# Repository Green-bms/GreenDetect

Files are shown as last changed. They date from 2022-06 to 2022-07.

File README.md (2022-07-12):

# GreenDetect
Opensource Wireless Sensor Network Platform (WSN) , for enviromental monitoring

## Description


Green Detect project was created with the aim of providing the community with a tool to monitor and control the environment.
The Green Detect network is independent of the Internet, so it can work even in geographic areas where the Internet is not present.
In the Green Detect local network it is possible to connect from 1 to 60 sensors that transmit their data via wireless through the ESP-NOW protocol to a computer where through the Green Detect application it is possible to monitor each individual sensor, detect alarm conditions, locate the sensors in an animated geographic map and record all acquisitions in order to collect all data for preventive and statistical purposes.
Each individual sensor module is powered by a supercapacitor (or Nimh batteries) charged by a solar panel.


Green Detect is Opensource: anyone can modify and improve the project, for example by adding new types of sensors.

## Web site
The project is described in detail at the following link: : https://hackaday.io/project/186064-green-detect

## Youtube presentation
https://youtu.be/CE9HRHpV6fQ
Subscribe please... :smile:

## Open source Development applications
The project was created using the following Open source applications:
- **KiCad** : to design sensor module
- **Arduino IDE** : to design the code of sensor module (ESP8266)
- **Visual Studio** : to design WIndows application in C# language
- **TinkerCad** : to design sensors and solar panel case for 3D printer

## Green Detect Windows application source code
The source code of Windows application is shared in the following repository: https://github.com/Green-bms/GreenDetect-Windows-Application

## Warning
This project is not commercial. This project is for educational and technological purposes.
No warrenty is foreseen.
Green BMS assumes no responsibility for any errors or inaccuracies that may appear in any documentation or file or any software that may be provided.
The use of this project is done entirely at your own risk and responsibility.
The use of this project may not be compliant with local laws or regulations.

## Open Source Hardware Certification
Green Detect has been certified as open source hardware by the Open Source Hardware Association, with the UID: IT000009.
Certificate link: (https://certification.oshwa.org/it000009.html)

## License

This work is licensed under a **Creative Commons Attribution-ShareAlike 4.0 International License**.
https://creativecommons.org/licenses/by-sa/4.0/

### You are free to:

**Share** — copy and redistribute the material in any medium or format

**Adapt**  — remix, transform, and build upon the material
for any purpose, even commercially.
This license is acceptable for Free Cultural Works.
The licensor cannot revoke these freedoms as long as you follow the license terms.

### Under the following terms:

**Attribution** — You must give appropriate credit, provide a link to the license, and indicate if changes were made. You may do so in any reasonable manner, but not in any way that suggests the licensor endorses you or your use.

**ShareAlike** — If you remix, transform, or build upon the material, you must distribute your contributions under the same license as the original.

**No additional restrictions** — You may not apply legal terms or technological measures that legally restrict others from doing anything the license permits.

### Notices:
You do not have to comply with the license for elements of the material in the public domain or where your use is permitted by an applicable exception or limitation.
No warranties are given. The license may not give you all of the permissions necessary for your intended use. For example, other rights such as publicity, privacy, or moral rights may limit how you use the material.

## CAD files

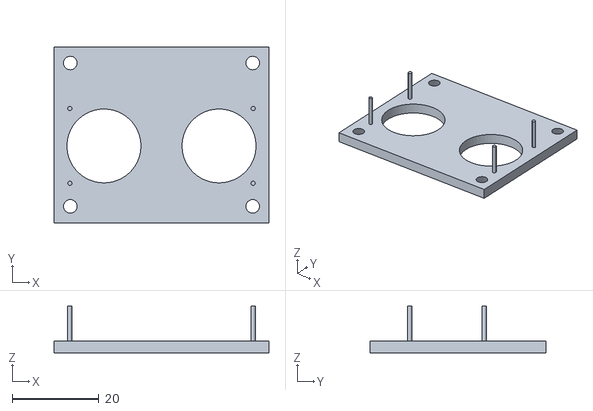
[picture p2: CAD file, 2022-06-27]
02 Sensors/Sensor type 01/3d printer box/SR04 case v0.3_cover.stl
49.5 x 40.5 x 10.8

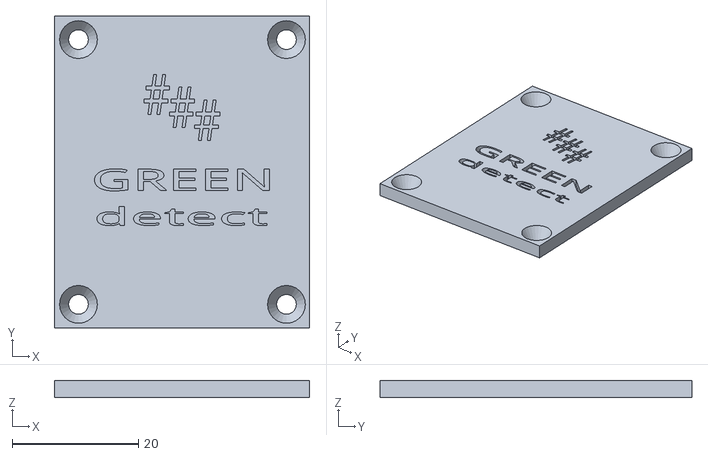
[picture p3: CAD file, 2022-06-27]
02 Sensors/Sensor type 02/3d printer box/Sensor2 case v0.0_cover.stl
40.5 x 49.5 x 2.75

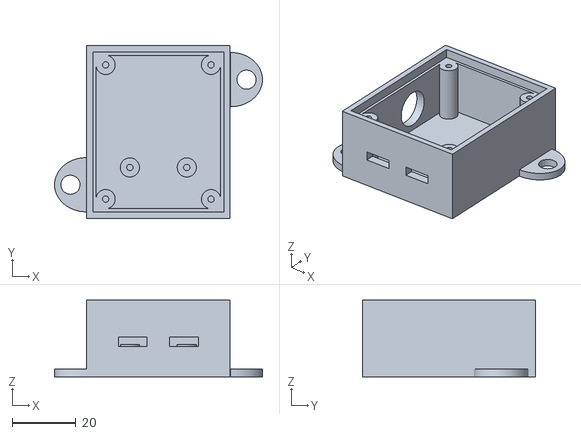
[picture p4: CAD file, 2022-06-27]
02 Sensors/Sensor type 04/3d printer box/Soil moinsture case v0.0.stl
65.1 x 54.0 x 24.0

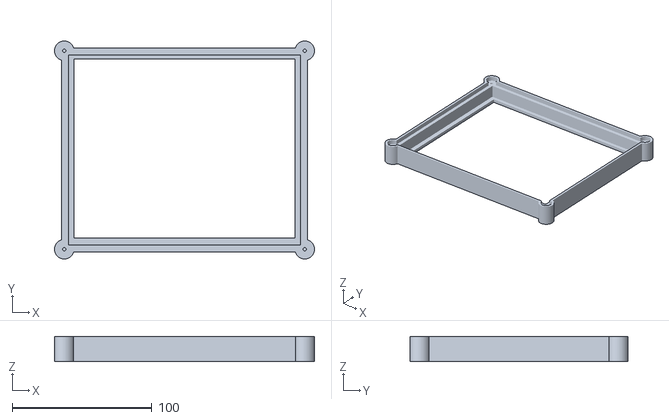
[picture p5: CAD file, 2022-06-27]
03 Solar panel/3d printer case/GreenDetect solar case front v.1.0.stl
186.0 x 156.0 x 18.0

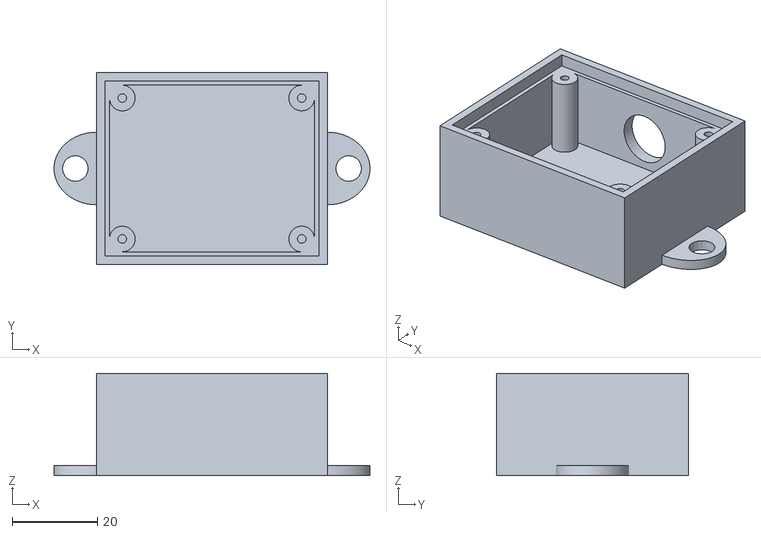
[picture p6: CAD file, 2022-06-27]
02 Sensors/Sensor type 01/3d printer box/SR04 case v0.3_box.stl
74.0 x 45.0 x 24.0

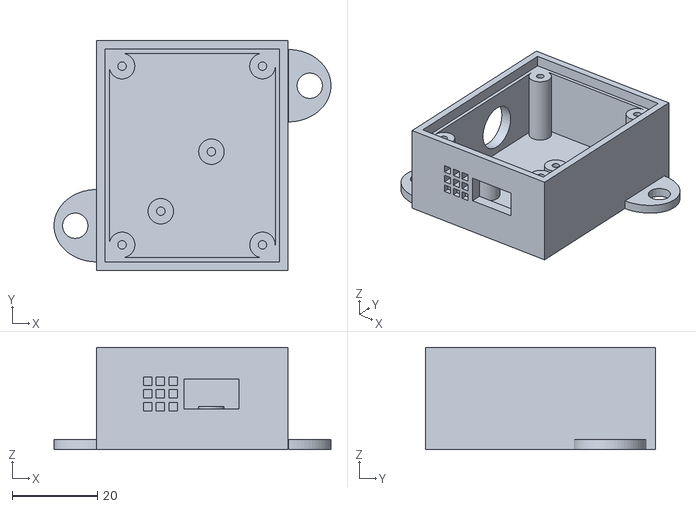
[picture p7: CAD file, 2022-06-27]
02 Sensors/Sensor type 02/3d printer box/Sensor2 case v0.0.stl
65.1 x 54.0 x 24.0

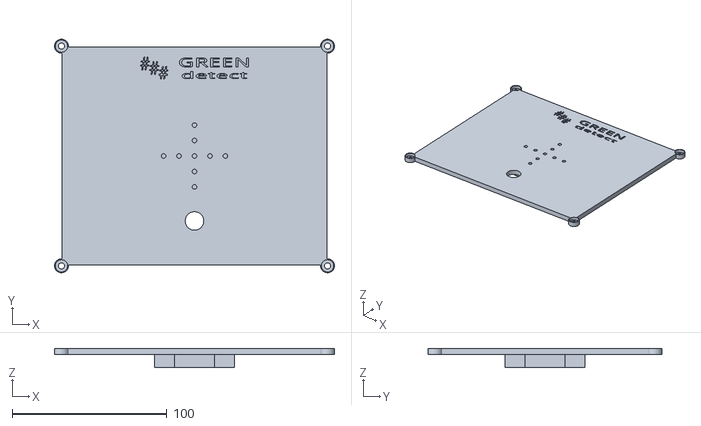
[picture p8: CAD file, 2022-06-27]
03 Solar panel/3d printer case/GreenDetect solar case back v.1.1.stl
181.0 x 151.0 x 12.5

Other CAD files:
02 Sensors/Sensor type 04/3d printer box/Soil moinsture case v0.0_cover.stl

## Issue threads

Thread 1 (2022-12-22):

Error installing Windows software

Arakistech, 2022-12-22:
When running setup.exe, I get this error: "El archivo GreenDetect.exe.config tiene un hash calculado distinto al especificado en el manifiesto."

Arakistech, 2022-12-22:
With the new download, I don´t get the error, but the program does not start.

Green-bms, 2022-12-22:
strange...

   try to check on windows app management if GreenDetect app is already present

   If yes, uninstall it and install again.

   If not try to restart the computer

   Da "Arakistech" ***@***.***
   A "Green-bms/GreenDetect" ***@***.***
   Cc "Green-bms" ***@***.***,"Comment" ***@***.***
   Data Thu, 22 Dec 2022 07:21:27 -0800
   Oggetto Re: [Green-bms/GreenDetect] Error installing Windows software (Issue #1)

   With the new download, I don´t get the error, but the program does not start.

   —
   Reply to this email directly, view it on GitHub, or unsubscribe.
   You are receiving this because you commented. Message ID: ***@***.***>

ahsanfi, 2023-02-09:
Hi, I also have error when installing the program. @Green-bms

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

**And this is the error detail:**
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

Green-bms, 2023-02-09:
Hi,

   first of all, check on windows app management if GreenDetect app is already present: If yes, uninstall it.

   After that, try to download Windows software from this link: https://hackaday.io/project/186064-green-detect

   go to files section and click on: 04 Win application.zip Bye. Sergio

   Da "Muhammad Ahsan Fillah Abadi" ***@***.***
   A "Green-bms/GreenDetect" ***@***.***
   Cc "Green-bms" ***@***.***,"Mention" ***@***.***
   Data Thu, 09 Feb 2023 01:31:27 -0800
   Oggetto Re: [Green-bms/GreenDetect] Error installing Windows software (Issue #1)

   Hi, I also have error when installing the program. @Green-bms

   And this is the error detail:

     PLATFORM VERSION INFO
     Windows : 10.0.22623.0 (Win32NT)
     Common Language Runtime : 4.0.30319.42000
     System.Deployment.dll : 4.8.9032.0 built by: NET481REL1
     clr.dll : 4.8.9105.0 built by: NET481REL1LAST_C
     dfdll.dll : 4.8.9032.0 built by: NET481REL1
     dfshim.dll : 10.0.22621.30000 (WinBuild.160101.0800)

     SOURCES
     Deployment url : file:///E:/OneDrive/OneDrive%20-%20Universitas%20Diponegoro/KEGIATAN%20LAIN/LOMBA/PKM%202023/SMART%20FOREST%20PROTECTOR/PROTOTYPE/GreenDetect-master/GreenDetect-master/04%20Win%20application/GreenDetect.application
     Application url : file:///E:/OneDrive/OneDrive%20-%20Universitas%20Diponegoro/KEGIATAN%20LAIN/LOMBA/PKM%202023/SMART%20FOREST%20PROTECTOR/PROTOTYPE/GreenDetect-master/GreenDetect-master/04%20Win%20application/Application%20Files/GreenDetect_1_0_0_44/GreenDetect.exe.manifest

     IDENTITIES
     Deployment Identity : GreenDetect.application, Version=1.0.0.44, Culture=neutral, PublicKeyToken=9ba089cdd6a5cde1, processorArchitecture=msil
     Application Identity : GreenDetect.exe, Version=1.0.0.44, Culture=neutral, PublicKeyToken=9ba089cdd6a5cde1, processorArchitecture=msil, type=win32

     APPLICATION SUMMARY
     * Installable application.

     ERROR SUMMARY
     Below is a summary of the errors, details of these errors are listed later in the log.
     * Activation of E:\OneDrive\OneDrive - Universitas Diponegoro\KEGIATAN LAIN\LOMBA\PKM 2023\SMART FOREST PROTECTOR\PROTOTYPE\GreenDetect-master\GreenDetect-master\04 Win application\GreenDetect.application resulted in exception. Following failure messages were detected:
          + File, GreenDetect.exe.config, has a different computed hash than specified in manifest.

     COMPONENT STORE TRANSACTION FAILURE SUMMARY
     No transaction error was detected.

     WARNINGS
     There were no warnings during this operation.

     OPERATION PROGRESS STATUS
     * [09/02/2023 16:28:43] : Activation of E:\OneDrive\OneDrive - Universitas Diponegoro\KEGIATAN LAIN\LOMBA\PKM 2023\SMART FOREST PROTECTOR\PROTOTYPE\GreenDetect-master\GreenDetect-master\04 Win application\GreenDetect.application has started.
     * [09/02/2023 16:28:43] : Processing of deployment manifest has successfully completed.
     * [09/02/2023 16:28:43] : Installation of the application has started.
     * [09/02/2023 16:28:43] : Processing of application manifest has successfully completed.
     * [09/02/2023 16:28:45] : Found compatible runtime version 4.0.30319.
     * [09/02/2023 16:28:45] : Request of trust and detection of platform is complete.

     ERROR DETAILS
     Following errors were detected during this operation.
     * [09/02/2023 16:28:46] System.Deployment.Application.InvalidDeploymentException (HashValidation)
          + File, GreenDetect.exe.config, has a different computed hash than specified in manifest.
          + Source: System.Deployment
          + Stack trace:
            at System.Deployment.Application.ComponentVerifier.VerifyFileHash(String filePath, Hash hash)
            at System.Deployment.Application.ComponentVerifier.VerifyFileHash(String filePath, HashCollection hashCollection)
            at System.Deployment.Application.ComponentVerifier.VerifyComponents()
            at System.Deployment.Application.DownloadManager.DownloadDependencies(SubscriptionState subState, AssemblyManifest deployManifest, AssemblyManifest appManifest, Uri sourceUriBase, String targetDirectory, String group, IDownloadNotification notification, DownloadOptions options)
            at System.Deployment.Application.ApplicationActivator.DownloadApplication(SubscriptionState subState, ActivationDescription actDesc, Int64 transactionId, TempDirectory& downloadTemp)
            at System.Deployment.Application.ApplicationActivator.InstallApplication(SubscriptionState& subState, ActivationDescription actDesc)
            at System.Deployment.Application.ApplicationActivator.PerformDeploymentActivation(Uri activationUri, Boolean isShortcut, String textualSubId, String deploymentProviderUrlFromExtension, BrowserSettings browserSettings, String& errorPageUrl, Uri& deploymentUri)
            at System.Deployment.Application.ApplicationActivator.PerformDeploymentActivationWithRetry(Uri activationUri, Boolean isShortcut, String textualSubId, String deploymentProviderUrlFromExtension, BrowserSettings browserSettings, String& errorPageUrl)
            --- End of stack trace from previous location where exception was thrown ---
            at System.Runtime.ExceptionServices.ExceptionDispatchInfo.Throw()
            at System.Deployment.Application.ApplicationActivator.PerformDeploymentActivationWithRetry(Uri activationUri, Boolean isShortcut, String textualSubId, String deploymentProviderUrlFromExtension, BrowserSettings browserSettings, String& errorPageUrl)
            at System.Deployment.Application.ApplicationActivator.ActivateDeploymentWorker(Object state)

     COMPONENT STORE TRANSACTION DETAILS
     No transaction information is available.

   —
   Reply to this email directly, view it on GitHub, or unsubscribe.
   You are receiving this because you were mentioned. Message ID: ***@***.***>

ahsanfi, 2023-02-09:
Thank you so much for your answer.
I have another question. Can I switch the Supercapacitor with 18650 Lithium Battery?

Sent from Mail<https://go.microsoft.com/fwlink/?LinkId=550986> for Windows

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

Green-bms, 2023-02-09:
No, you can't replace with lithium batteries: different voltage, different charging circuit.
You can replace Supercap with 2s Nimh batteries: this is an option of the project.
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

ahsanfi, 2023-02-09:
OK, thank you. Have you any preferences what Nimh batteries can I use?

Sent from Mail<https://go.microsoft.com/fwlink/?LinkId=550986> for Windows

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

Green-bms, 2023-02-09:
I suggest to use 2 x batteries AA 2800 mA Nimh, with a dedicated holder.
This is an example of batteries: https://www.amazon.com/POWEROWL-Rechargeable-Batteries-Capacity-Discharge/dp/B07M7JGTP7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
This is an example of holder: https://www.amazon.com/WAYLLSHINE-2Pcs-Battery-Holder-Leads/dp/B09V7Z4MT7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

ahsanfi, 2023-02-09:
Thank you so much ❤️

Sent from Mail<https://go.microsoft.com/fwlink/?LinkId=550986> for Windows

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

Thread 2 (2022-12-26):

Some of the components 3D is not visible in Kicad

Arakistech, 2022-12-26:
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

Arakistech, 2022-12-26:
I was not able to create the 3D model of the whole PCB maybe due to missing parts models. I would like to get the 3D model of the PCB to test it along with the enclosure 3D.

Green-bms, 2022-12-27:
Hi,
It looks like you don't have the main Kicad libraries installed.
download them from here: https://kicad.github.io/
to associate them with the Green detect project, you need to save the libraries in the following locations:

- symbols (.lib .dcm files) on C:\Program Files\KiCad\share\kicad\library
- footprints (.pretty folders) on C:\Program Files\KiCad\share\kicad\modules
- 3d models (.3dshapes folders) on C:\Program Files\KiCad\share\kicad\modules\packages3d\

Bye.

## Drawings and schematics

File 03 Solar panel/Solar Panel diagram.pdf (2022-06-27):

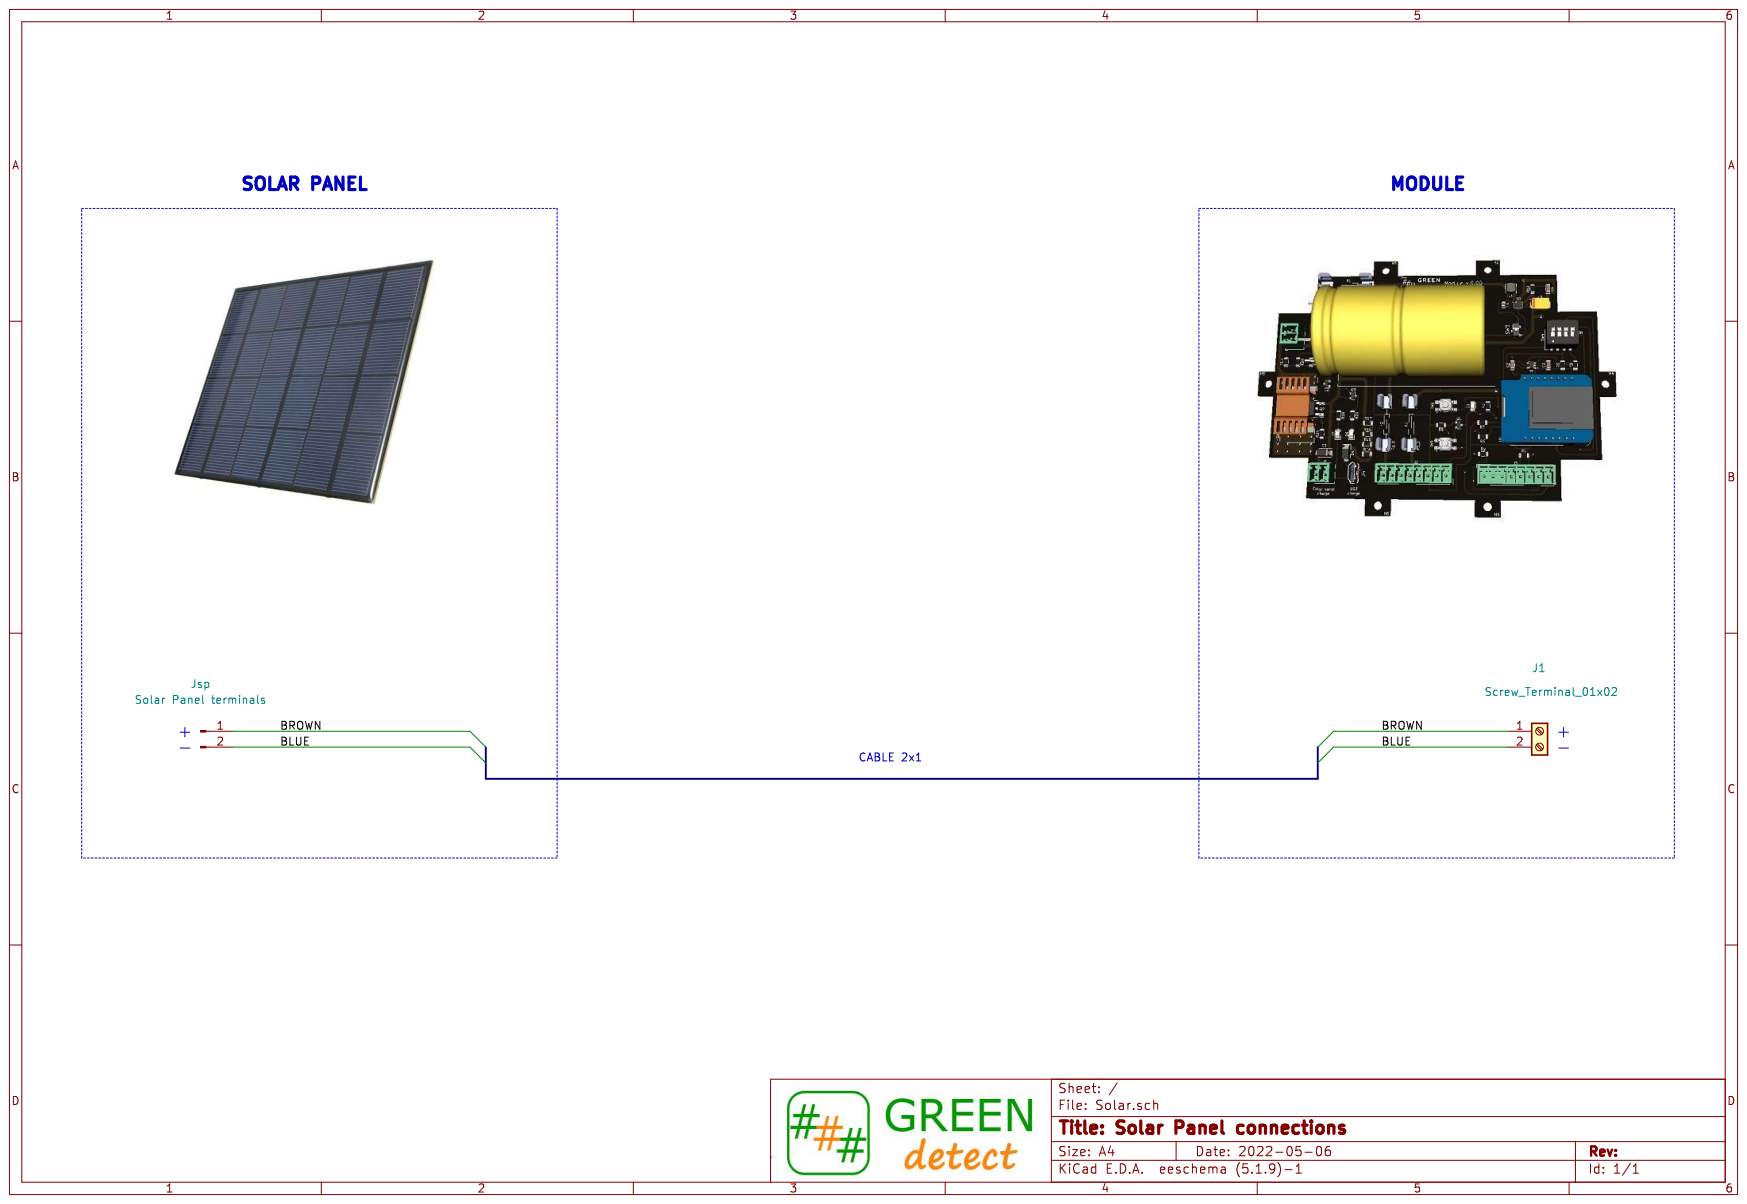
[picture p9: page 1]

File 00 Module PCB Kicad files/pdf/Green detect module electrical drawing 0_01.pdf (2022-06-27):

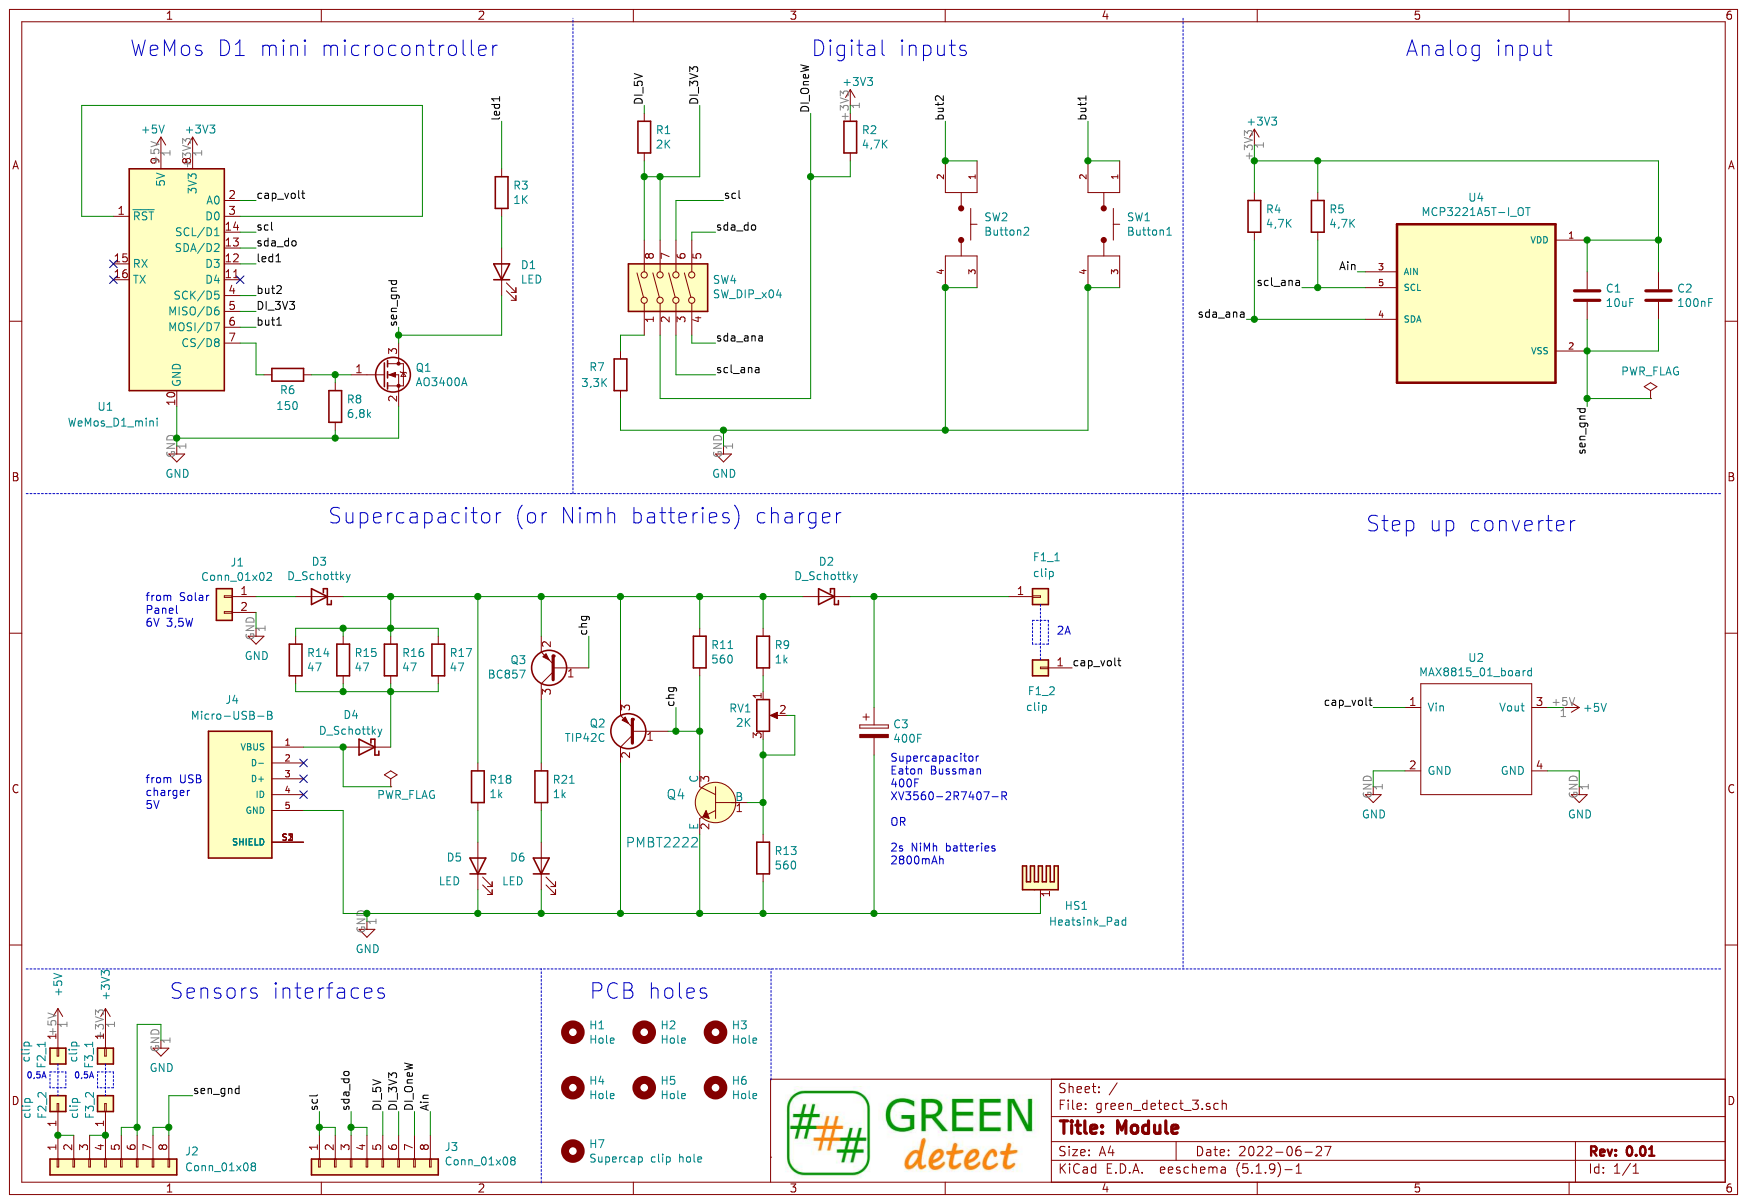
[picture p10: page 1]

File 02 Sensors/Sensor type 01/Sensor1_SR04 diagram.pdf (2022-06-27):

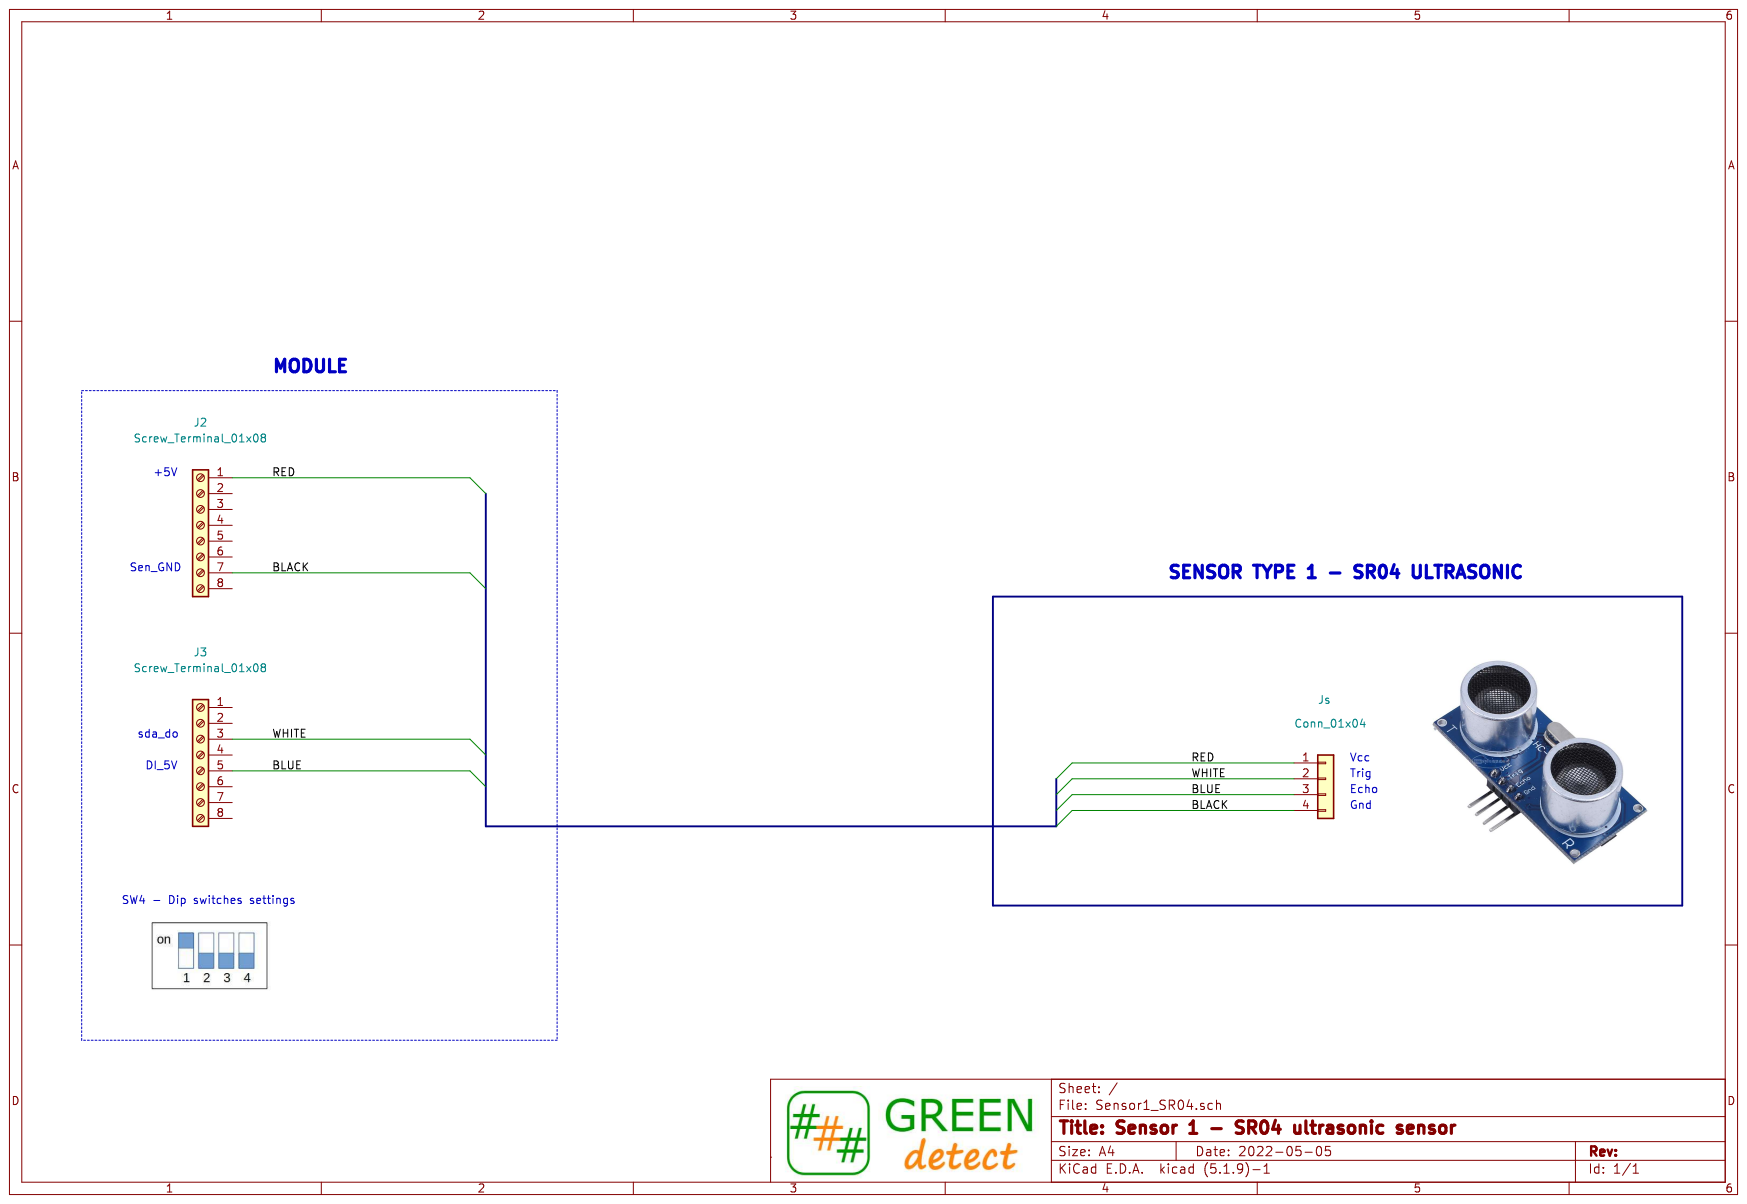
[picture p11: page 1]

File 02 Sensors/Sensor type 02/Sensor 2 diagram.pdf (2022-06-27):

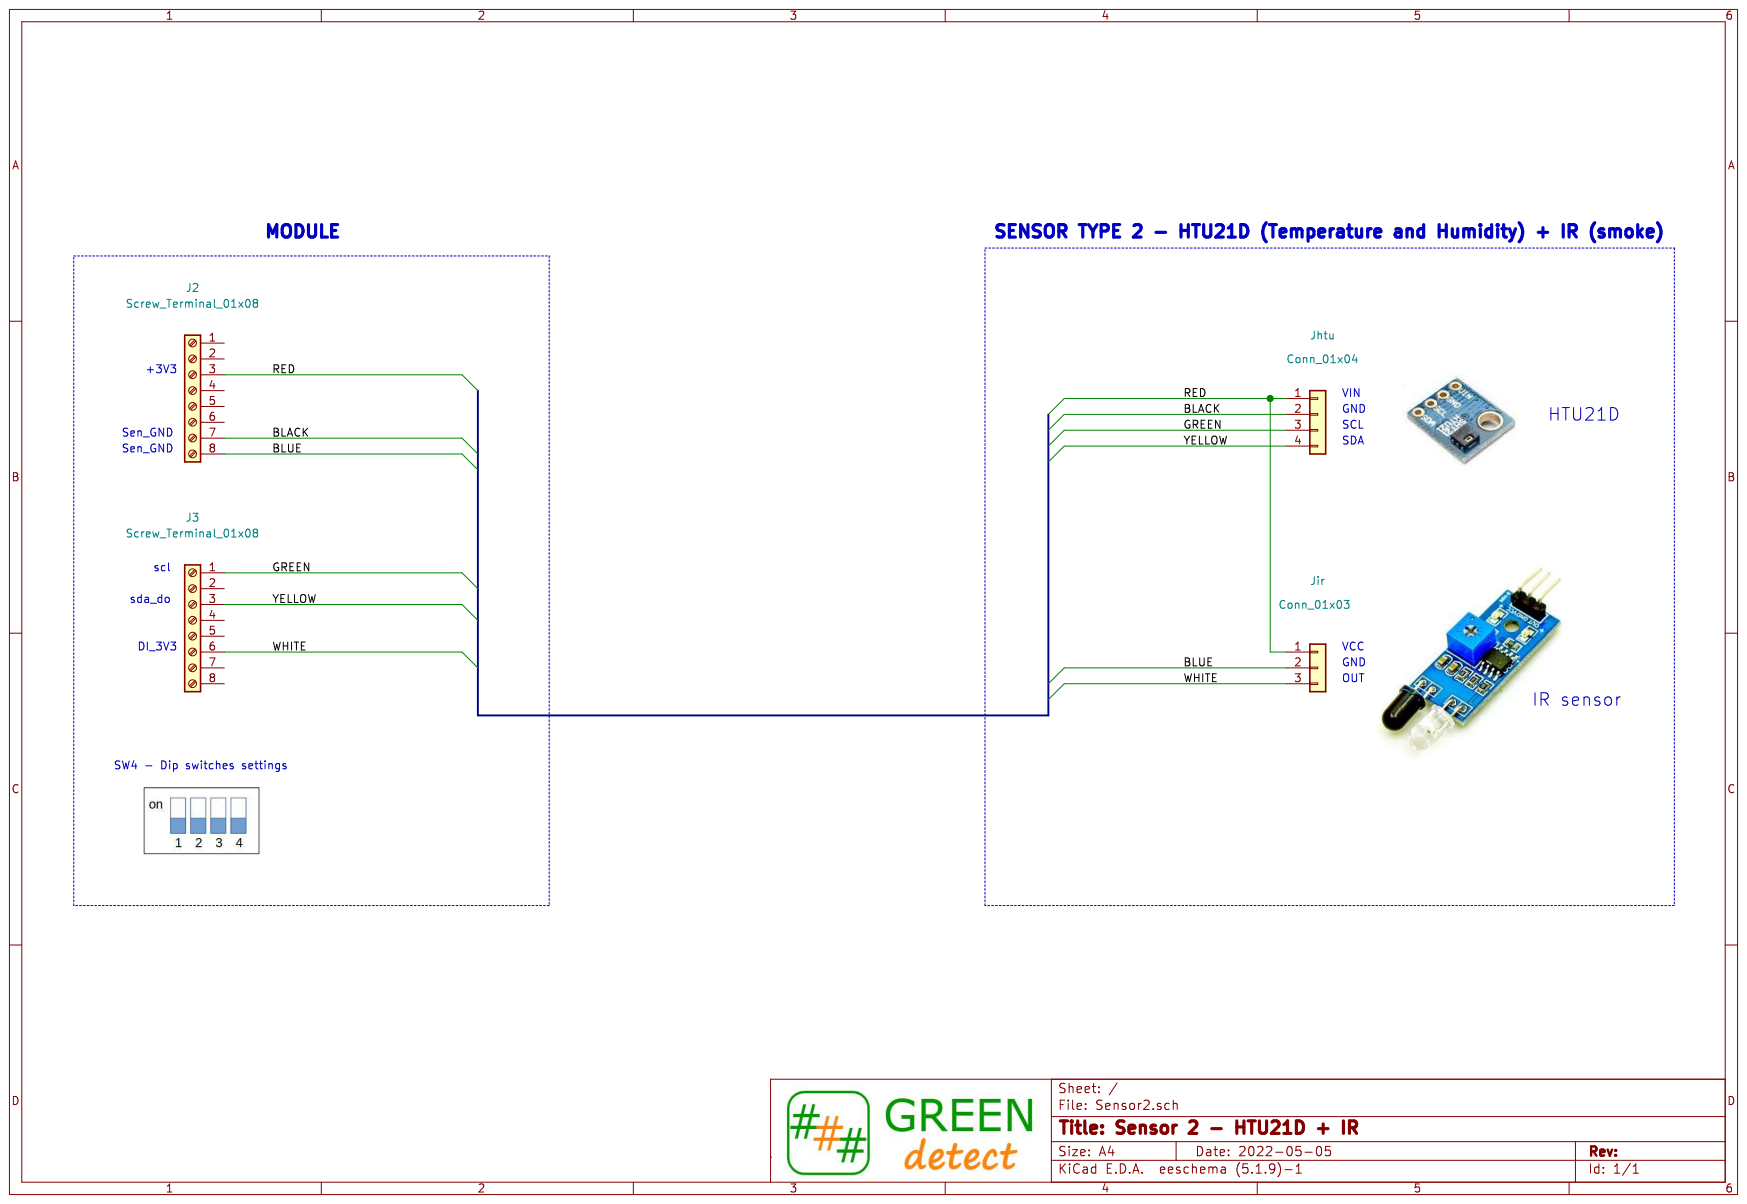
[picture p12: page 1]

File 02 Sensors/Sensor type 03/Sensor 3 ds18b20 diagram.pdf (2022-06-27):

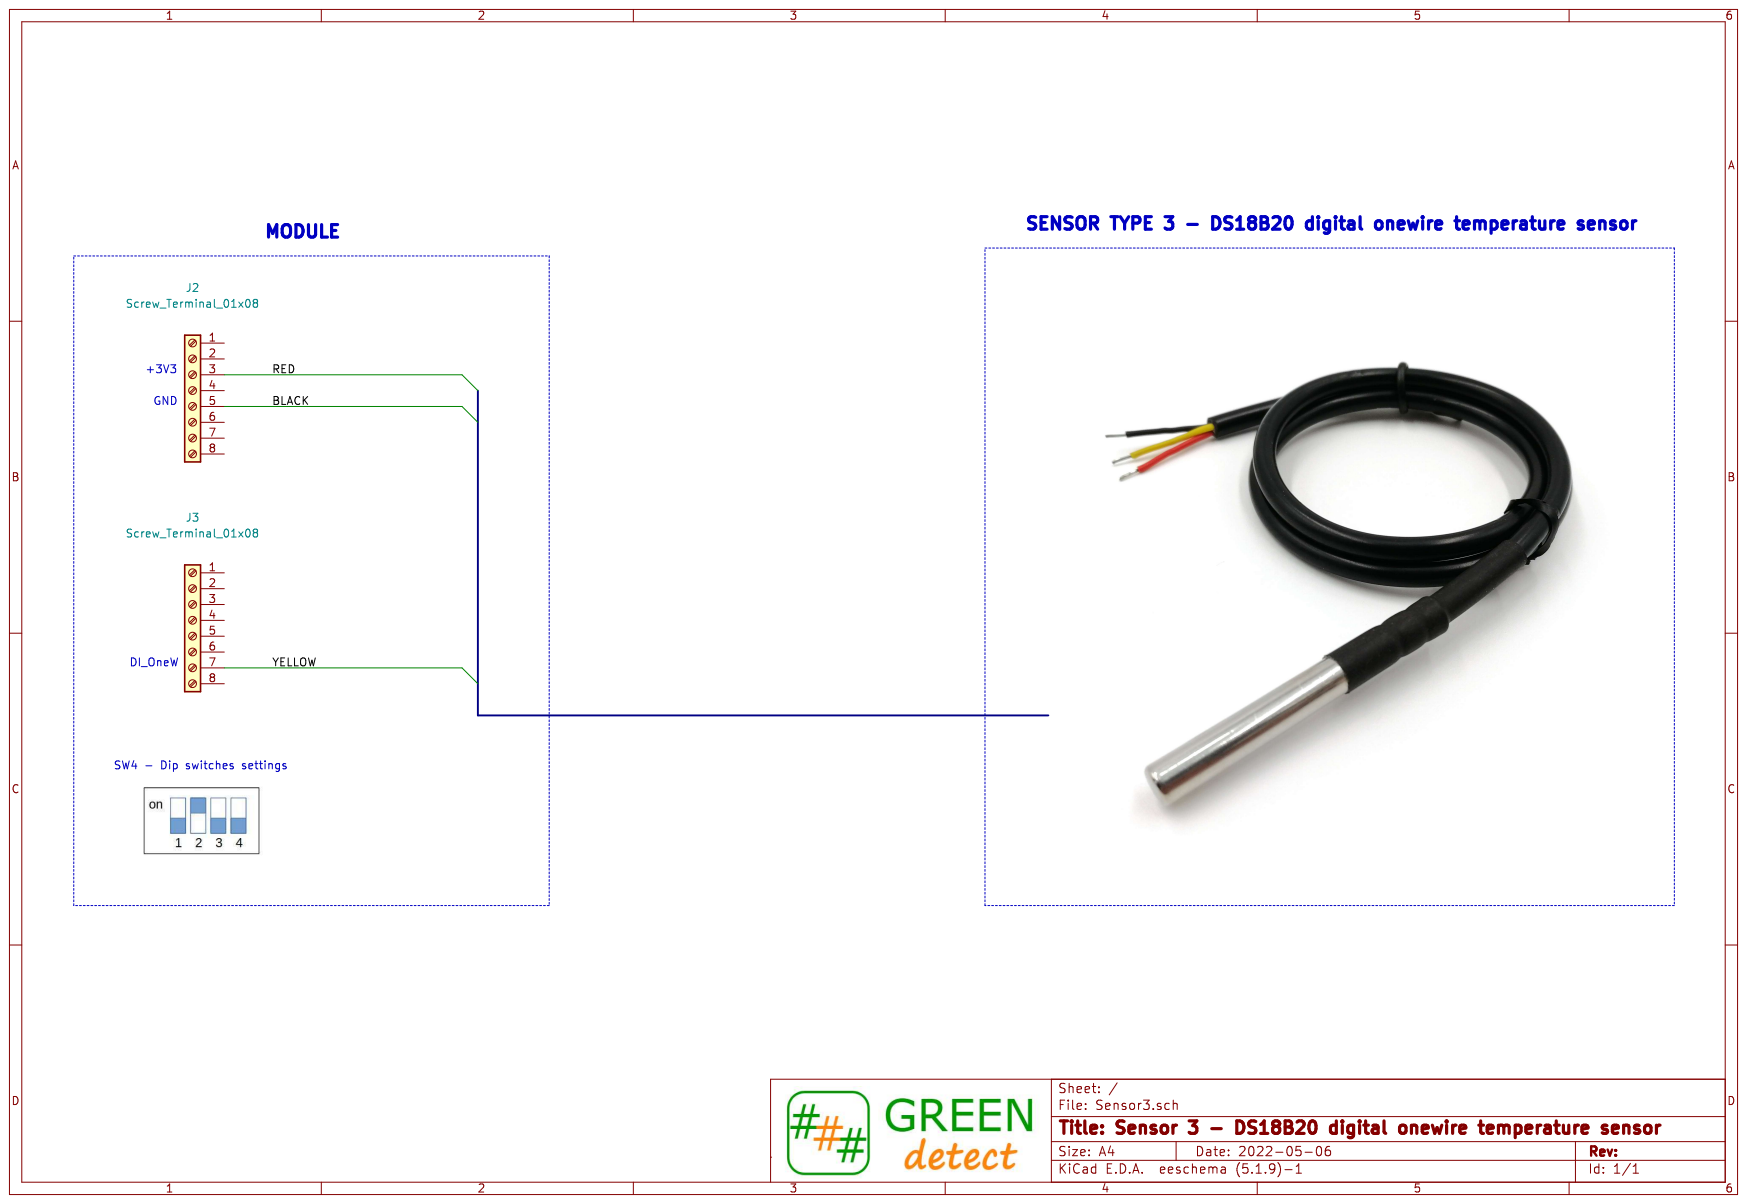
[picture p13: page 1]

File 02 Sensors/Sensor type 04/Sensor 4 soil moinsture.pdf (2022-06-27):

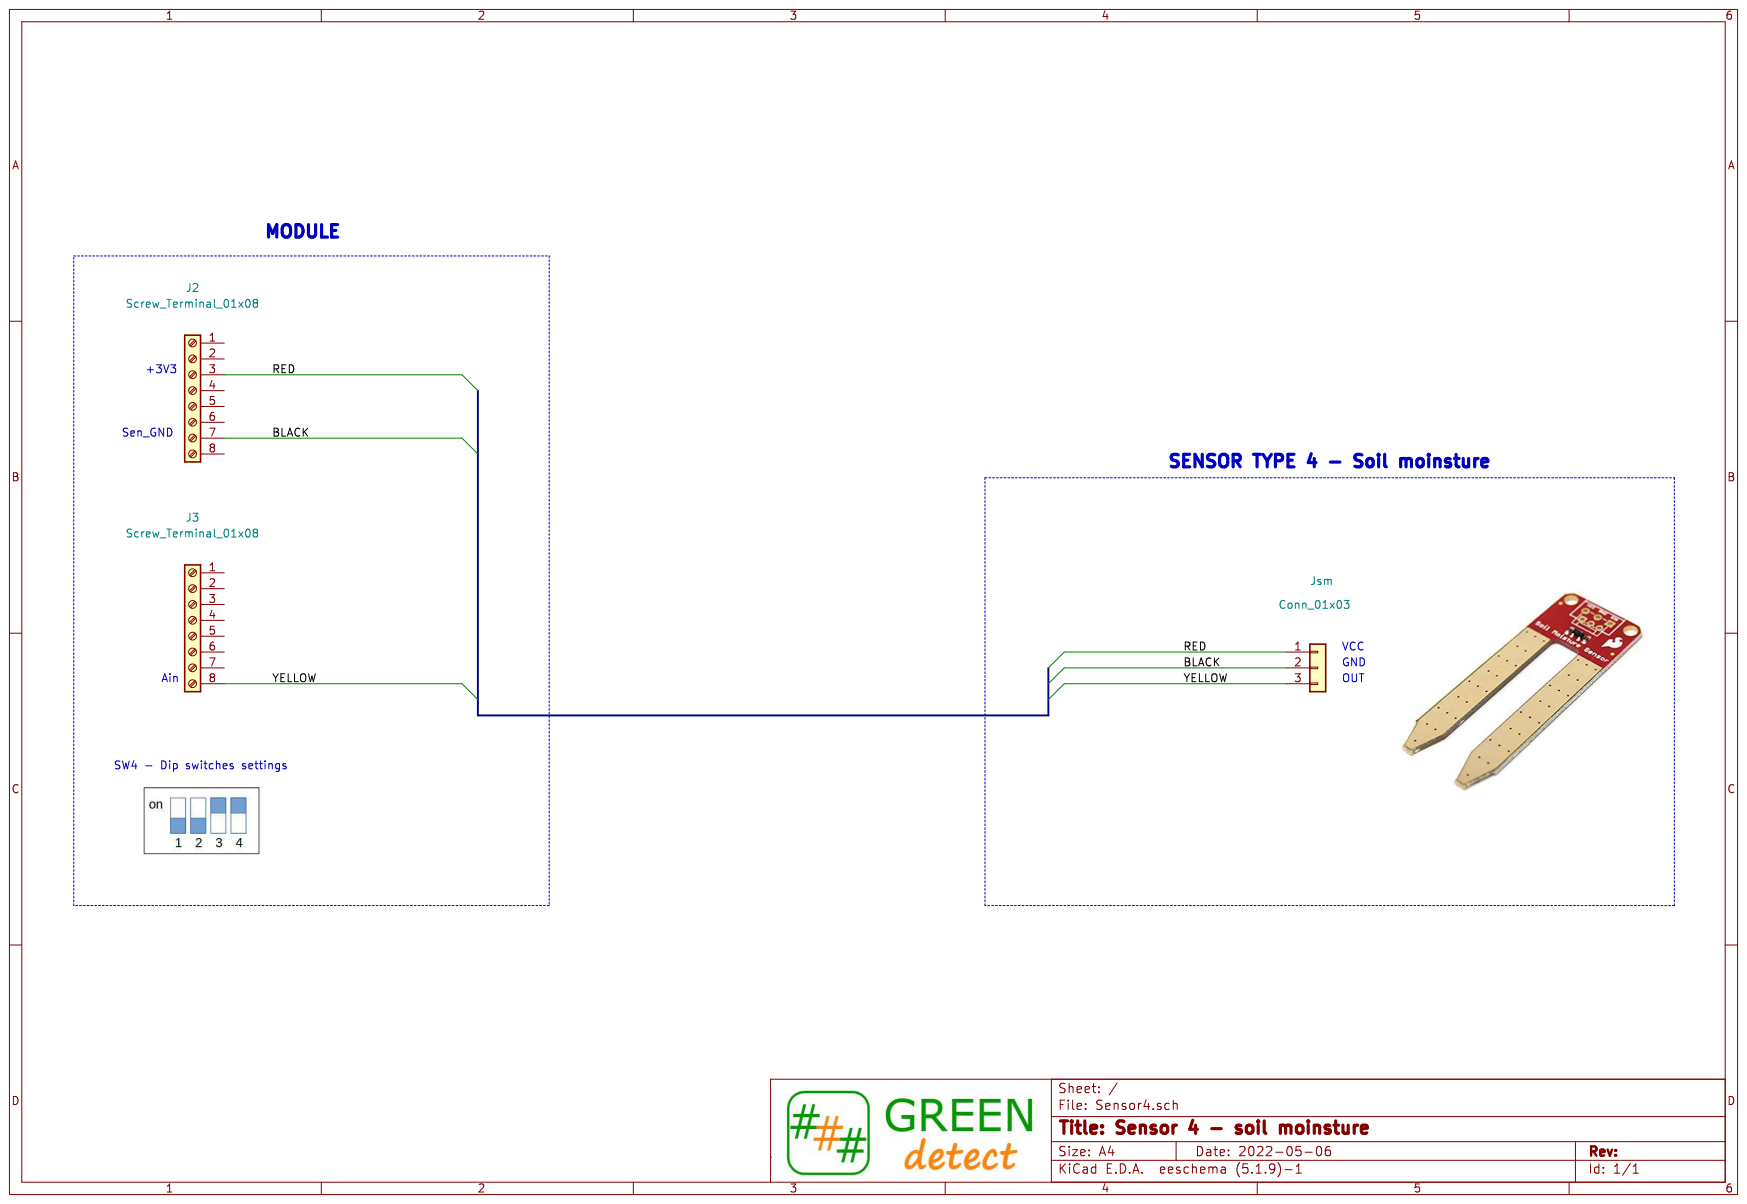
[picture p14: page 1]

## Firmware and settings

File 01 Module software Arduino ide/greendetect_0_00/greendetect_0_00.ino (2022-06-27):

/*
  Green Detect module


 Wireless Sensor Module with ESP-NOW protocol
 
 The module works according to the following steps:

1. sensor signal acquisition

2. receiving data from the previous form

3. data transmission to the next module

4. Deep sleep mode (30 seconds)


  Versions:

  - Ver. 0.00 date 27/06/2022 created by Sergio Ghirardelli (first release)

*/



#include <ESP8266WiFi.h>
#include <espnow.h>
#include "functions_5.h"
#include <EEPROM.h>
#include <Wire.h>
#include "SparkFunHTU21D.h"
#include <OneWire.h>
#include <DallasTemperature.h>

#include <Wire.h>
#include "MCP3X21.h"  






const uint8_t mcp3221_address = 0x4D;
const uint16_t ref_voltage = 3300;  // in mV
uint16_t MCP3221_channel;

MCP3221 mcp3221(mcp3221_address);



HTU21D htu21d_sensor;

unsigned long t, t0, t1, sample;

int i, n, z, k, x; //counters

//SR04 sensor
long duration, distance;
int distance_int;
int test_dist;

//htu21d sensor
float htu21d_temp, htu21d_hum;
int htu21d_temp_int, htu21d_hum_int;
byte htu21d_temp_byte, htu21d_hum_byte;

bool ir_input; //IR sensor
bool module_test; //module test

//supercap voltage measuring
int a0_channel, vx, vx_lim, vx_perc;
byte soc;

// Onewire DS18B20 temperature sensor
const int oneWireBus = 12;
OneWire oneWire(oneWireBus);
DallasTemperature sensors(&oneWire);
float onewire_temp;
int onewire_temp_int;

byte first_code; // code written in case of first use

//variables for program modes
unsigned long u_elapsed, u_count, da_elapsed, da_count;
unsigned long both_elapsed, both_count;
unsigned long net_elapsed, net_count;
bool osc, but_u, but_da, u, da, both, both_p, both_mem, prog, prog_p, prog_mem, prog_n, prog_mem2, osc_n, osc_mem, prog1, prog1_n, prog_mem3;
bool u_n, u_mem, da_n, da_mem, wdt_test;
int u_number, da_number, new_address, u_led_preset, u_led_elapsed, da_led_preset, da_led_elapsed, address, sleep_time, new_sleep_time, sensor_type, new_sensor_type, gain_offset, prog_step, deep_set;
byte last_set, fault_mode;


//variables used for transmission
byte send_step;
bool wait_n, wait_n_mem;
int app_time;
unsigned long lastTime;
unsigned long timerDelay;
unsigned long comp_time;
byte val1, val2, val3;
bool wait, wait_q;
unsigned long wait_elapsed, wait_count;
bool gateway_send;
bool deltime, deltime_q;
unsigned long deltime_elapsed, deltime_count;

unsigned long time_start, time_stop, life_start, life_stop; //variables to measure task time
unsigned long deep_time; // deep sleep time
bool send_ok;
bool pippo;

// Starting receiver address set
uint8_t broadcastAddress[] = {0x16, 0x16, 0x16, 0x16, 0x16, 0x00};

// Starting sensor module address
uint8_t newMACAddress[] = {0x16, 0x16, 0x16, 0x16, 0x16, 0x00};

// data structure
typedef struct struct_data {
  byte battery_soc[60];
  byte data1[60];
  byte data2[60];
  byte data3[60];
  byte sync_time;
  byte life;
  byte number;
} struct_data;

// structures
struct_data data_send;
struct_data data_rec;
struct_data data_internal;

//variables used to check previous module fault
bool timeout, timeout_q;
unsigned long timeout_elapsed, timeout_count, timeout_set;

//task time management
bool task, task_q;
unsigned long task_elapsed, task_count;
unsigned long advance_time;
long offset_time;

// Callback when data is sent
void OnDataSent(uint8_t *mac_addr, uint8_t sendStatus) {
  //Serial.println("Last Packet Send Status: ");
  if (sendStatus == 0) {
      send_ok = true;
  }
  else {
   // Serial.println("Delivery fail");
      send_ok = false;
  }
}


// Callback function that will be executed when data is received. Received data is copied in internal data variables.
void OnDataRecv(uint8_t * mac, uint8_t *incomingData, uint8_t len) {
  memcpy(&data_rec, incomingData, sizeof(data_rec));

  if ((address > 1) && (address <= 60)) {

    for ( i = 1; i < address; i++) {

      data_internal.battery_soc[i] = data_rec.battery_soc[i];
      data_internal.data1[i] = data_rec.data1[i];
      data_internal.data2[i] = data_rec.data2[i];
      data_internal.data3[i] = data_rec.data3[i];
    }

    data_internal.sync_time = data_rec.sync_time;
    data_internal.life = data_rec.life;
   
  }



  if (address == 99) {
    data_internal.number = data_rec.number;
   
    for ( i = 1; i <= data_internal.number; i++) {

      data_internal.battery_soc[i] = data_rec.battery_soc[i];
      data_internal.data1[i] = data_rec.data1[i];
      data_internal.data2[i] = data_rec.data2[i];
      data_internal.data3[i] = data_rec.data3[i];
    }

    data_internal.sync_time = data_rec.sync_time;
    data_internal.life = data_rec.life;
    
    gateway_send = true; 
    serial_transmission();

  }


}


void setup() {
  life_start = micros();
  
  // disable WIFI
  WiFi.mode(WIFI_OFF);

  //pin configuration
  pinMode(LED_BUILTIN, OUTPUT);
  pinMode(15, OUTPUT); //mosfet enable
  pinMode(12, INPUT); // Sensor Digital input (SR04 echo, IR, etc)
  pinMode(13, INPUT_PULLUP); // Button 1
  pinMode(14, INPUT_PULLUP); // Button 2
  pinMode(0, OUTPUT); //led 1



  //reading from EEprom, if first code is different from 114 it means that Eeprom is empty
  EEPROM.begin(9);
  first_code = EEPROM.read(3);

  if (first_code == 114) {
    address = EEPROM.read(0);
    last_set = EEPROM.read(2);
    sleep_time = EEPROM.read(4);
    sensor_type = EEPROM.read(6);
    fault_mode = EEPROM.read(8);
  }
  else {
    address = 0;
    last_set = 0;
    sleep_time = 50;
    sensor_type = 0;
    fault_mode = 0;
  }

  EEPROM.end();


 

  //Sensor Digital output (SR04 trig)
  if ((address != 99) && (sensor_type == 1)) {
    pinMode (4, OUTPUT);
  }

  //sensors supply mosfet activation
  digitalWrite(15, HIGH);

  //Onewire DS18B20 sensor setup
  if ((address != 99) && (sensor_type == 3)) {
    sensors.setWaitForConversion(false);
    sensors.requestTemperatures();
  }


  //MCP3221 ADC setup
  #if defined(ESP8266) || defined(ESP32)
  Wire.begin(SDA, SCL);
  mcp3221.init(&Wire);
  #else
  mcp3221.init();
  #endif


  //delay time for sensors start up
  delay (100);

  //variables initialization
  new_address = address;
  newMACAddress [5] = address;
  x = 0;
  k = 0;
  wdt_test = 0;
  lastTime = 0;
  timerDelay = 10;
  sample = 0;
  gateway_send = false;
  data_internal.life = 0;
  wait = true;
  task = false;
  timeout = false;
  send_step = 0;
  distance = 0;
  deep_set = 30;
  ir_input = false ;
  pippo = false;
  
  
  //module address management
  if (address == 0) {
    broadcastAddress [5] = 0x0; //module not addressed
  }
  else {
    if (last_set) {
      broadcastAddress [5] = 0x63; //when the module is the last, the recipient address is 0x63
    }
    else {
      broadcastAddress [5] = address + 1; //set the recipient address to the next address of the group
    }
  }


  //if both buttons are pressed, set the program mode
  if ((!digitalRead(13)) && (!digitalRead(14))) {
    prog_step = 1;
    prog = true;
    u_number = 1;
    da_number = 1;
  }
  else {
    prog_step = 0;
    prog = false;
    u_number = 0;
    da_number = 0;
  }

  //if only button2 is pressed, a memory reset is done
  if ((digitalRead(13)) && (!digitalRead(14))) {
    first_code = 0;
    EEPROM.begin(9);
    EEPROM.write(3, first_code);
    EEPROM.commit();
    EEPROM.end();
    delay (10);
    ESP.restart();
  }


  // Init Serial Monitor
  Serial.begin(115200);





  //Sensors reading
  if (address != 99) {

    //supercap voltage
    a0_channel = analogRead(A0);
    vx = map (a0_channel, 0, 1023, 0, 3100);
    vx_lim = constrain(vx, 1500, 3000);
    vx_perc = map (vx_lim, 1500, 3000, 0, 60);
    soc = byte (vx_perc);

    //sensor test button set the bit 7 of soc byte
    if (!digitalRead(13)) {
      module_test = true;
    }
    if (module_test) {
      bitSet(soc, 7);
    }

     //ADC analog input 
     MCP3221_channel = mcp3221.read();
    
    //sensor type = 0 --> repeater
    if (sensor_type == 0) {      
      val1 = 255;
      val2 = 255;
      val3 = 255;      
    }

    //sensor type = 1 --> SR04 ultrasonic distance sensor
    if (sensor_type == 1) {      
      digitalWrite(4, LOW);
      delayMicroseconds(2);
      digitalWrite(4, HIGH);
      delayMicroseconds(10);
      digitalWrite(4, LOW);
      duration = pulseIn(12, HIGH, 20000);
      distance = duration / 58.2;
      distance_int = int (distance);
      val1 = distance_int & 0xff;
      val2 = (distance_int >> 8);
      val3 = 0;    
    }

    //sensor type = 2 --> HTU21D temperature + humidity I2C sensor
    if (sensor_type == 2) {      
      htu21d_sensor.begin();
      htu21d_temp = htu21d_sensor.readTemperature();
      htu21d_hum = htu21d_sensor.readHumidity();
      float temp_x10 = htu21d_temp * 10;
      htu21d_temp_int = int (temp_x10);
      htu21d_hum_int = int (htu21d_hum);
      htu21d_hum_byte = byte (htu21d_hum_int);
      val1 = htu21d_temp_int & 0xff;
      val2 = (htu21d_temp_int >> 8);
      val3 = htu21d_hum_byte;
      if (!digitalRead(12)) {
        ir_input = true ;
      }
      if (ir_input) {
        bitSet(soc, 6);
      }
      
    }

    //sensor type = 3 --> Onewire DS18B20 temperature sensor
    if (sensor_type == 3) {
      
      onewire_temp = sensors.getTempCByIndex(0);
      float temp_x10 = onewire_temp * 10;
      onewire_temp_int = int (temp_x10);
      val1 = onewire_temp_int & 0xff;
      val2 = (onewire_temp_int >> 8);
      val3 = 0;
     
    }


    //sensor type = 4 --> Soil moisture sensor
   
    if (sensor_type == 4) {      
      val1 = MCP3221_channel & 0xff;
      val2 = (MCP3221_channel >> 8);
      val3 = 0;           
      }

    //to measure sensor type reading time 
    /*time_start = micros();
    
    time_stop = micros() - time_start; 
    Serial.println ("jk");
    Serial.println (time_stop); */



  }

  //sensors supply mosfet deactivation
  digitalWrite(15, LOW);

  // Set device as a Wi-Fi Station
  WiFi.mode(WIFI_STA);
  WiFi.setOutputPower(10); 
  wifi_set_macaddr(STATION_IF, &newMACAddress[0]);

  // Init ESP-NOW
  if (esp_now_init() != 0) {
    Serial.println("Error initializing ESP-NOW");
    return;
  }

  // Set ESP-NOW Role
  esp_now_set_self_role(ESP_NOW_ROLE_COMBO);

  // Once ESPNow is successfully Init, we will register for Send CB to
  // get the status of Trasnmitted packet
  esp_now_register_send_cb(OnDataSent);

  // Register peer
  esp_now_add_peer(broadcastAddress, ESP_NOW_ROLE_COMBO, 1, NULL, 0);

  // Register for a callback function that will be called when data is received
  esp_now_register_recv_cb(OnDataRecv);

  send_ok = false;
  deltime = false;
  deltime_q = false;
}




void loop() {

  

  /*Push buttons managements*/
  but_u = !digitalRead(13); //digital channels reading
  but_da = !digitalRead(14);
  u = TON(but_u, 50, u_elapsed, u_count); //buttons must be pressed for at least 50 msec
  da = TON(but_da, 50, da_elapsed, da_count);
  both = TON ((u and da), 3000, both_elapsed, both_count);//both buttons are pressed for 3 seconds
  both_p = PosTrig(both, both_mem); //positive edge of both variable
  prog_p = PosTrig(prog, prog_mem); //positive edge of prog: when program mode is set
  prog_n = NegTrig(prog, prog_mem2); //negative edge of prog: when program mode is reset
  prog1_n = NegTrig(prog1, prog_mem3); //negative edge of prog1: when program mode 1 is reset
  u_n = NegTrig(u, u_mem); //negative edge of u: when SW1 button is released
  da_n = NegTrig (da, da_mem); //negative edge of da: when SW2 button is released

  //oscillator for blinking
  if (millis() - t >= sample)
  {
    osc = !osc;
    t += sample;
  }


  /*Program mode or Normal mode calling*/
  if (prog_step == 1) {
    program();
  }

  else if (prog_step == 2) {
    prog_last();
  }


  else if (prog_step == 3) {
    prog_time();
  }

  else if (prog_step == 4) {
    prog_type();
  }

  else if (prog_step == 0) {
    normal();
  }


  
  test_dist =  data_internal.data2[1] << 8 | data_internal.data1[1];


  
  

  //serial monitor
/*  Serial.println (MCP3221_channel);
   Serial.print (" ");
    Serial.println (var);*/



}// end of loop



//normal mode
void normal () {


  if (prog_p) { // executed one time at the end of program mode. The new address set is stored and microcontroller reset

    digitalWrite(LED_BUILTIN, LOW); // both leds on to show the end of program mode
    digitalWrite(0, HIGH);
    address = new_address;
    sensor_type = new_sensor_type;


    EEPROM.begin(9);
    EEPROM.write(0, address);
    EEPROM.write(2, last_set);
    EEPROM.write(6, sensor_type);
    EEPROM.write(8, 0);

    if (first_code != 114) { //first EEprom address write
      first_code = 114;
      EEPROM.write(3, first_code);
    }
   /* if (address == 1) { //first EEprom address write
      sleep_time = new_sleep_time;
      EEPROM.write(4, sleep_time);
    }

    if ((address > 1) && (address <= 60)) { //first EEprom address write
      sleep_time = 60;
      EEPROM.write(4, sleep_time);
    }*/

    sleep_time = new_sleep_time;
    EEPROM.write(4, sleep_time);

    EEPROM.commit();
    EEPROM.end();

    newMACAddress [5] = address;
    n = address;
    delay(3000); //three seconds of freezing before starting the normal mode
    digitalWrite(0, LOW);
    ESP.restart();
  }


  if (both_p) {    //in case of pressing of both buttons for 3 seconds, system starts program mode
    prog = true;
    prog_step = 1;
  }

  //oscillator for gateway sending
  if (millis() - t >= 10)
  {
      if ((address==99) && (!gateway_send)) {
        Serial.println ("%");     
      }
    t += 10;
  }

  //task time management
  /*task_q = TON (!task, 120, task_elapsed, task_count);
    if (!task_q) {normal_sensor();}
    else {normal_send();}*/
  normal_send();

} // end of Normal mode




/*Program Mode to set the sensor module esp-now address*/
void program() {

  if (prog_p) {// executed one time at the start of program mode
    sample = 300;// sample time of leds blinking management (in msec)
    digitalWrite(15, HIGH);
    /*decrement of tens and units numbers*/
    u_number--;
    da_number--;
    u_led_elapsed = 0;
    da_led_elapsed = 0;
    digitalWrite(LED_BUILTIN, LOW); // both leds on to show the end of program mode
    digitalWrite(0, HIGH);
    delay(3000); //three seconds of freezing before starting the program mode
    digitalWrite(0, LOW);
    prog = false;
  }

  if (both_p) {    //in case of pressing of both buttons for 3 seconds, system soes to next program step
    if (new_address == 99) {
      prog = true;
      prog_step = 4;
    }
    else {
      prog = true;
      prog_step = 2;
    }

  }

  if (u_n) { //increment of units value after SW1 button release
    u_number++;
  }
  if (da_n) { //increment of tens value after SW2 button release
    da_number++;
  }
  if (u_number > 9) { //restart of units value
    u_number = 0;
  }
  if (da_number > 9) { //restart of tens value
    da_number = 0;
  }
  new_address = (da_number * 10) + u_number; //new address number calculation

  /*preset values of leds blink mangement */
  u_led_preset = u_number + 2;
  da_led_preset = da_number + 2;
  osc_n = NegTrig(osc, osc_mem);



  if (osc)
  {
    if ((u_led_elapsed >= 1) && (u_led_elapsed <= u_number)) { //blinking of Units led to show the set value
      digitalWrite(0, HIGH);
    }
    else  {
      digitalWrite(0, LOW);
    }

    if ((da_led_elapsed >= 1) && (da_led_elapsed <= da_number)) { //blinking of Tens led to show the set value
      digitalWrite(LED_BUILTIN, LOW);
    }
    else  {
      digitalWrite(LED_BUILTIN, HIGH);
    }

  }
  else
  {
    digitalWrite(0, LOW);
    digitalWrite(LED_BUILTIN, HIGH);
  }

  if (osc_n) //led blinking counters increment or reset every negative edge of the oscillator
  {
    u_led_elapsed++;
    if (u_led_elapsed > u_led_preset) {
      u_led_elapsed = 0;
    }
    da_led_elapsed++;
    if (da_led_elapsed > da_led_preset) {
      da_led_elapsed = 0;
    }
  }

}


/*Program step to set the sensor module as last of the network*/
void prog_last() {

  if (prog_p) { // executed one time at the end of program mode
    sample = 50; //led flashlight sample time (in msec)
    digitalWrite(LED_BUILTIN, LOW); // both leds on to show the end of program mode
    digitalWrite(0, HIGH);
    last_set = 0;
    delay(3000); //three seconds of freezing before starting the normal mode
    digitalWrite(0, LOW);
    prog = false;
  }


  if (both_p) {    //in case of pressing of both buttons for 3 seconds, system returnes to normal mode
    prog = true;
    prog_step = 4;
  }



  if (da_n) {
    last_set = 1; //set module as last of the whole battery pack
  }
  if (u_n) {
    last_set = 0; //set module as not the last of the whole battery pack
  }

  //if module is set as the last, builtin led flashlight, else led1 flashlights
  if (osc) {

    if (last_set == 1) {
      digitalWrite(LED_BUILTIN, LOW);
      digitalWrite(0, LOW);
    }
    else {
      digitalWrite(LED_BUILTIN, HIGH);
      digitalWrite(0, HIGH);
    }

  }

  else {

    digitalWrite(0, LOW);
    digitalWrite(LED_BUILTIN, HIGH);

  }
}


/*Program Mode to set the synchronization time for all the sensors (only if address is set to 1)*/
void prog_time() {

  if (prog_p) {// executed one time at the start of program mode
    sample = 300;// sample time of leds blinking management (in msec)

    /*decrement of tens and units numbers*/
    u_number = -1;
    da_number = -1;
    u_led_elapsed = 0;
    da_led_elapsed = 0;
    digitalWrite(LED_BUILTIN, LOW); // both leds on to show the end of program mode
    digitalWrite(0, HIGH);
    delay(3000); //three seconds of freezing before starting the program mode
    digitalWrite(0, LOW);
    prog = false;
  }

  if (both_p) {    //in case of pressing of both buttons for 3 seconds, system returnes to normal mode
    prog = true;
    prog_step = 0;
  }

  if (u_n) { //increment of units value after SW1 button release
    u_number++;
  }
  if (da_n) { //increment of tens value after SW2 button release
    da_number++;
  }
  if (u_number > 9) { //restart of units value
    u_number = 0;
  }
  if (da_number > 9) { //restart of tens value
    da_number = 0;
  }
  new_sleep_time = (da_number * 10) + u_number; //new address number calculation

  /*preset values of leds blink mangement */
  u_led_preset = u_number + 2;
  da_led_preset = da_number + 2;
  osc_n = NegTrig(osc, osc_mem);



  if (osc)
  {
    if ((u_led_elapsed >= 1) && (u_led_elapsed <= u_number)) { //blinking of Units led to show the set value
      digitalWrite(0, HIGH);
    }
    else  {
      digitalWrite(0, LOW);
    }

    if ((da_led_elapsed >= 1) && (da_led_elapsed <= da_number)) { //blinking of Tens led to show the set value
      digitalWrite(LED_BUILTIN, LOW);
    }
    else  {
      digitalWrite(LED_BUILTIN, HIGH);
    }

  }
  else
  {
    digitalWrite(0, LOW);
    digitalWrite(LED_BUILTIN, HIGH);
  }

  if (osc_n) //led blinking counters increment or reset every negative edge of the oscillator
  {
    u_led_elapsed++;
    if (u_led_elapsed > u_led_preset) {
      u_led_elapsed = 0;
    }
    da_led_elapsed++;
    if (da_led_elapsed > da_led_preset) {
      da_led_elapsed = 0;
    }
  }

}



/*Program Mode to set the sensor type*/
void prog_type() {

  if (prog_p) {// executed one time at the start of program mode
    sample = 300;// sample time of leds blinking management (in msec)

    /*decrement of tens and units numbers*/
    u_number = -1;
    da_number = -1;
    u_led_elapsed = 0;
    da_led_elapsed = 0;
    digitalWrite(LED_BUILTIN, LOW); // both leds on to show the end of program mode
    digitalWrite(0, HIGH);
    delay(3000); //three seconds of freezing before starting the program mode
    digitalWrite(0, LOW);
    prog = false;
  }

  if (both_p) {    //in case of pressing of both buttons for 3 seconds, system returnes to normal mode

    if (new_address == 1) {
      prog = true;
      prog_step = 3;
    }
    else {
      prog = true;
      prog_step = 0;
    }

   

  }

  if (u_n) { //increment of units value after SW1 button release
    u_number++;
  }
  if (da_n) { //increment of tens value after SW2 button release
    da_number++;
  }
  if (u_number > 9) { //restart of units value
    u_number = 0;
  }
  if (da_number > 9) { //restart of tens value
    da_number = 0;
  }
  new_sensor_type = (da_number * 10) + u_number; //new address number calculation

  /*preset values of leds blink mangement */
  u_led_preset = u_number + 2;
  da_led_preset = da_number + 2;
  osc_n = NegTrig(osc, osc_mem);



  if (osc)
  {
    if ((u_led_elapsed >= 1) && (u_led_elapsed <= u_number)) { //blinking of Units led to show the set value
      digitalWrite(0, HIGH);
    }
    else  {
      digitalWrite(0, LOW);
    }

    if ((da_led_elapsed >= 1) && (da_led_elapsed <= da_number)) { //blinking of Tens led to show the set value
      digitalWrite(LED_BUILTIN, LOW);
    }
    else  {
      digitalWrite(LED_BUILTIN, HIGH);
    }

  }
  else
  {
    digitalWrite(0, LOW);
    digitalWrite(LED_BUILTIN, HIGH);
  }

  if (osc_n) //led blinking counters increment or reset every negative edge of the oscillator
  {
    u_led_elapsed++;
    if (u_led_elapsed > u_led_preset) {
      u_led_elapsed = 0;
    }
    da_led_elapsed++;
    if (da_led_elapsed > da_led_preset) {
      da_led_elapsed = 0;
    }
  }

}


// first task
void normal_sensor() {
  digitalWrite(LED_BUILTIN, HIGH);
  
  }
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
